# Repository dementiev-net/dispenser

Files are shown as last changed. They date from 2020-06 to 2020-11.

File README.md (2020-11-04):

Дозатор флюса и пасты
=====================

Дозатор с экраном для настройки и отображения режима работы.
При выдавливании есть возможность отката, чтобы снималось напряжение и флюс не продолжал течь.

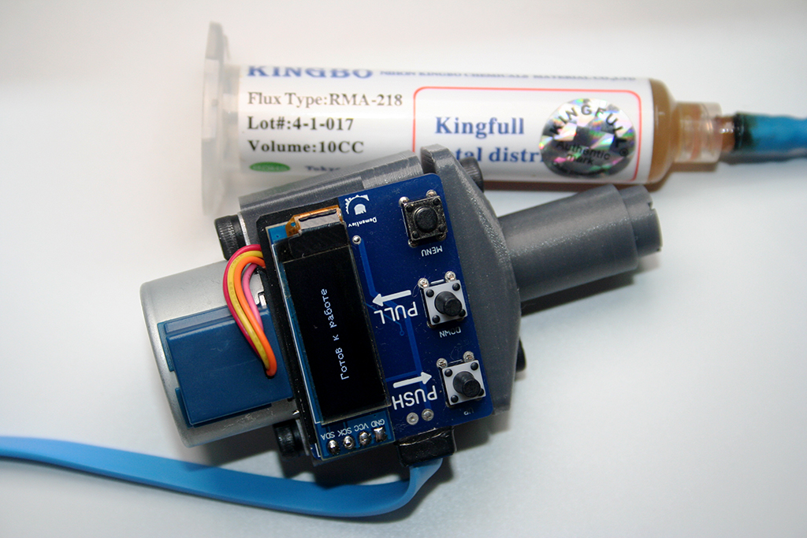
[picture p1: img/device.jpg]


## Плата

Управление:

* При нажатии на **первую кнопку (UP)** происходит выдавливание флюса и откат;
* **Вторая кнопка (DOWN)** отвечает за реверс. Повторное нажатие остановка;
* Чтобы войти в меню удерживается **третья кнопка (MENU)**;

| Верх | Низ
|---|---
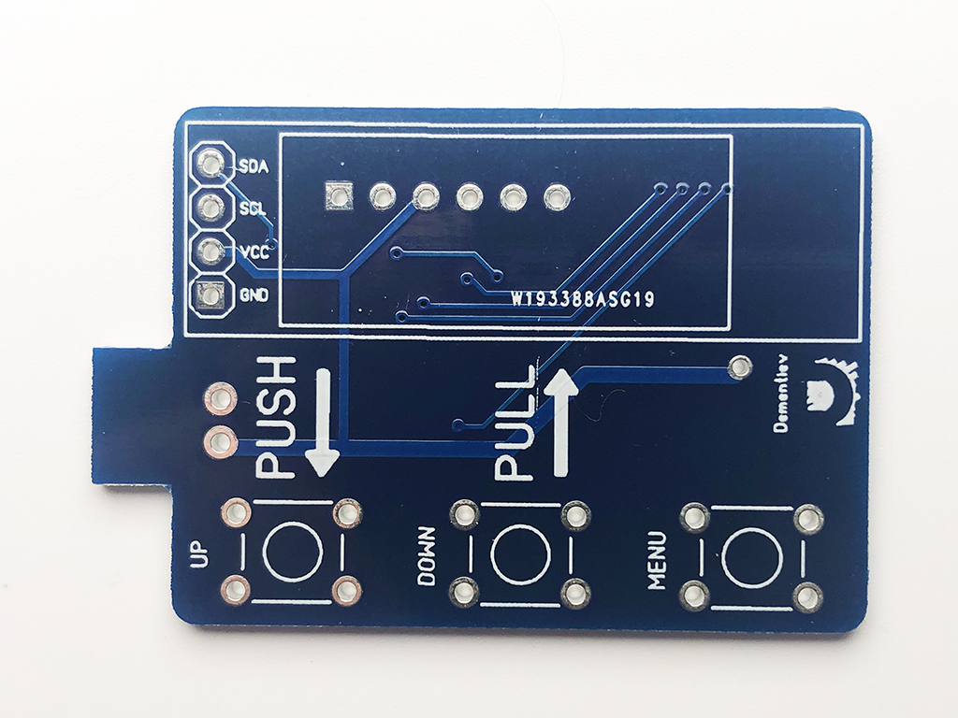
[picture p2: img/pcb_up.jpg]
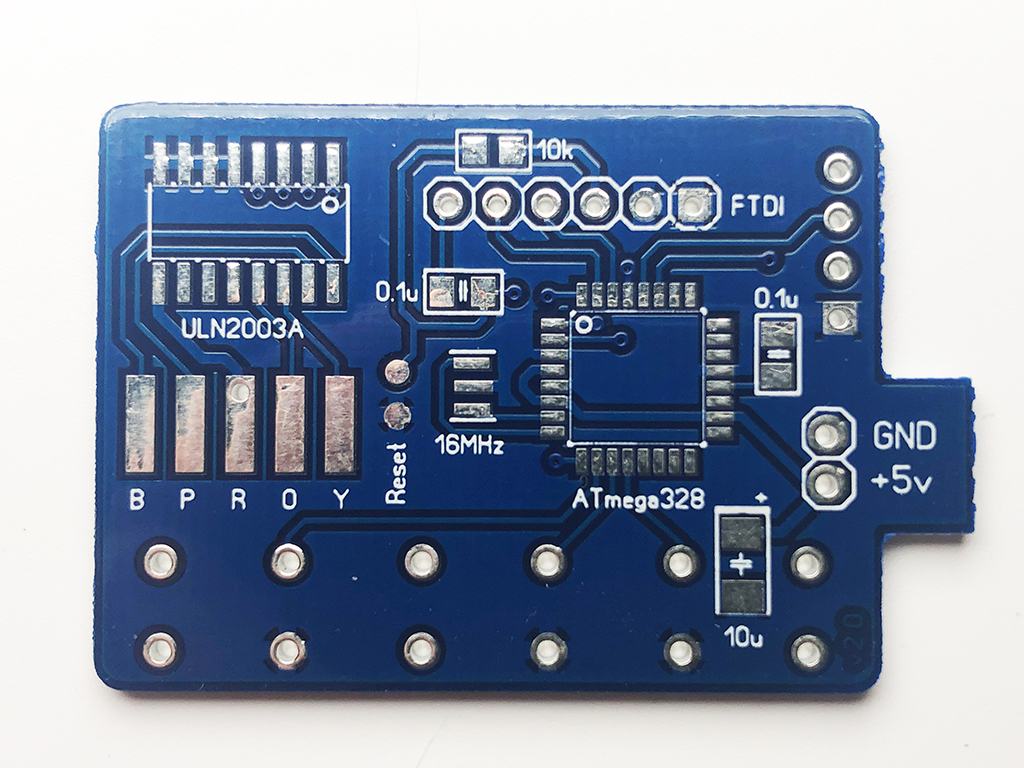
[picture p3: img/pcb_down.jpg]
|  | 
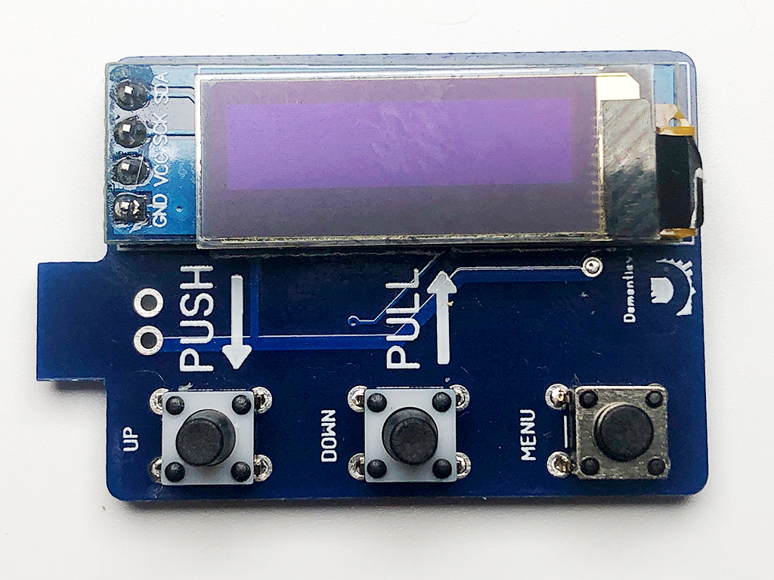
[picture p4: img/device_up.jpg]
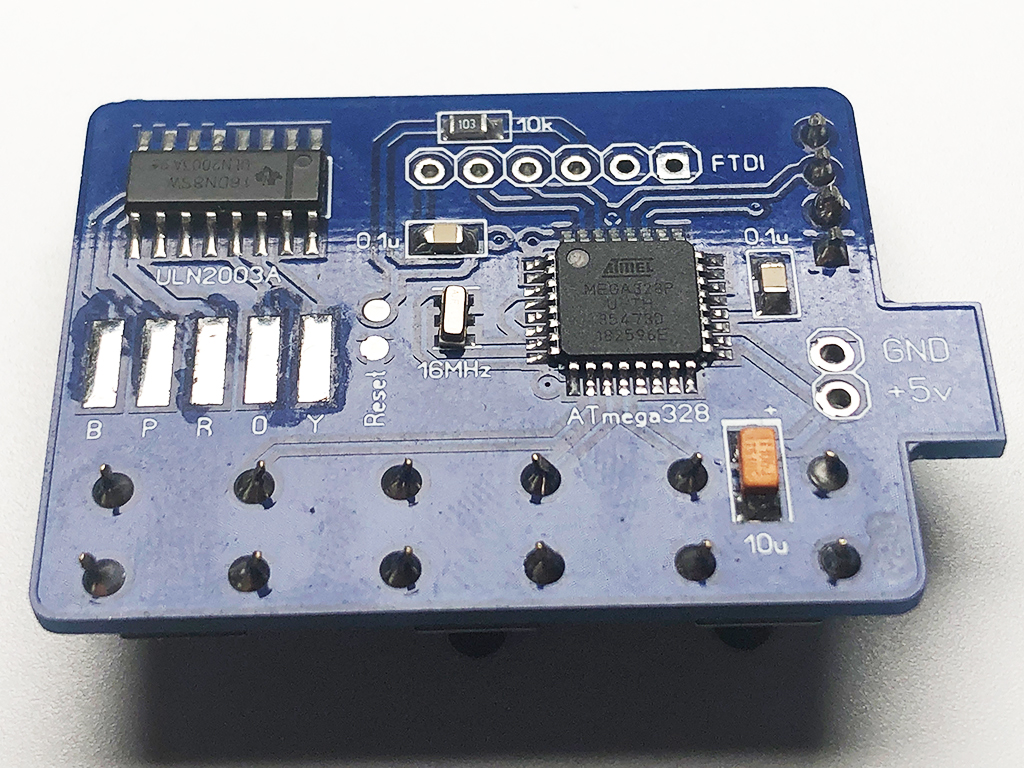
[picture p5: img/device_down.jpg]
|  | 

Экран:

* На **первом экране** настраиваются параметры выдавливания: ускорение, скорость и количество шагов с значениями от 0 до 100 и шагом в 5 пунктов. Листается меню третьей кнопкой а изменяются значения первыми двумя;
* На **втором экране** настройки отвечающие за откат. Значения и управление аналогичны выдавливанию;
* Для **сохранения настроек** в память удерживается третья кнопка;

| Первый экран | Настройки | Настройки
|---|---|---
|  |  | 

#### BOM:

|No|Name|Value|Layer|Comment
|---|---|---|---|---
|1|B1|Button|Top|
|2|B2|Button|Top|
|3|B3|Button|Top|
|4|C1|0.1u|Bottom|0805
|5|C2|0.1u|Bottom|0805
|6|C3|10u|Bottom|Tantal
|7|Q1|16Mhz|Bottom
|8|R1|10k|Bottom|0805
|9|SCREEN|0.91 OLED|Top|I2C 128x32
|10|U1|Atmega328|Bottom|TQFP-32
|11|U2|ULN2003A|Bottom|SO-16

## Корпус

Корпус и поршень с резьбой полностью распечатан на 3D принтере. Есть два варианта крепления платы к корпусу. К первой плата приклеивается на двусторонний скотч или "термоклей", во вторую вставляется. Какой удобнее решайте сами.

| Полный набор | Версии корпуса
|---|---
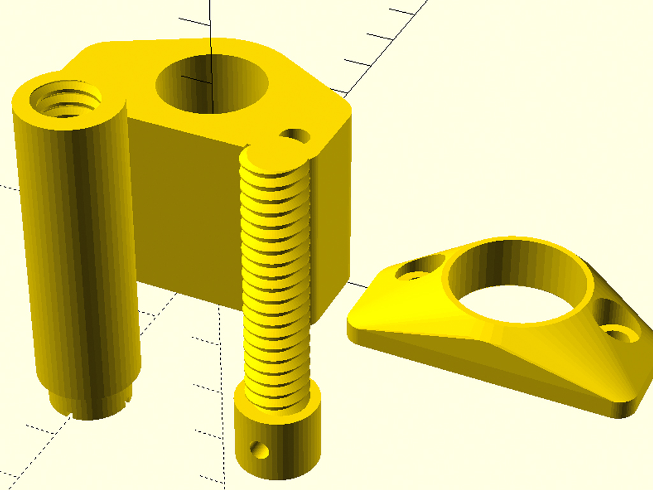
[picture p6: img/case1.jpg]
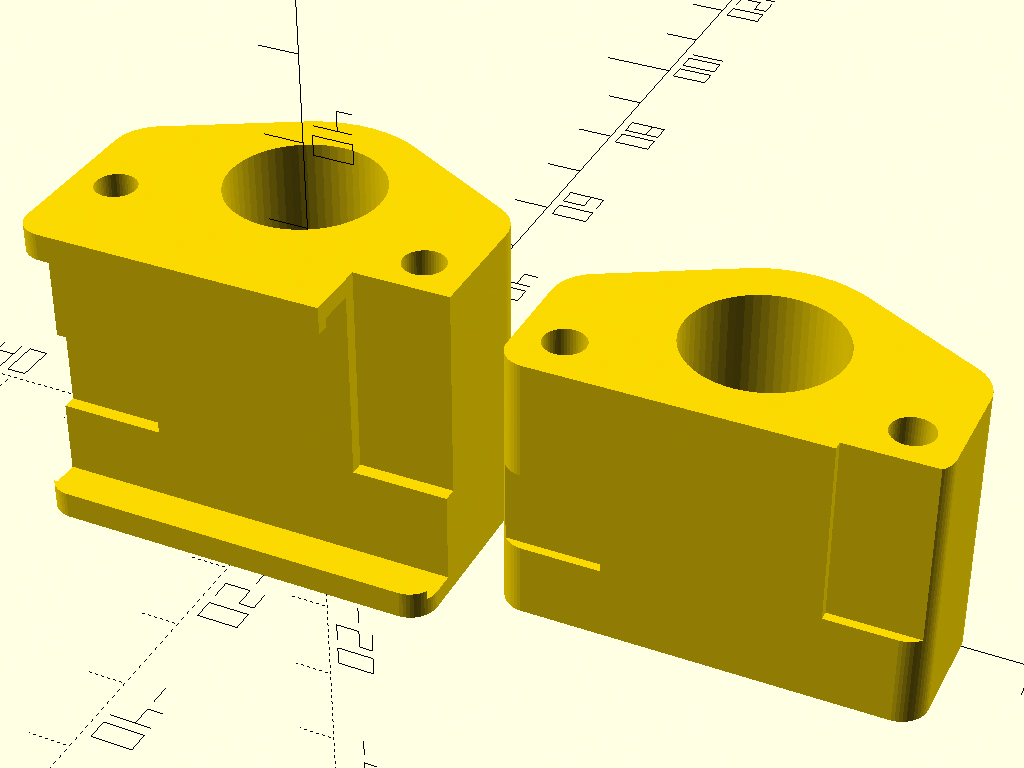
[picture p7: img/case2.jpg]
|  | 

## Прошивка

* Любым программатором загружается bootloader (HEX файл и фьюзы прилагаются). Самой простой вариант прошить через USB Arduino NANO и "сдуть" с нее чип.
* Впаивается чип на плату.
* Заливается INO файл из Arduino IDE (как Arduino NANO) с помощью USB-UART преобразователя (FTDI).

## Контакты

Связаться со мной: info@dementiev.net

##### Лицензия: «Attribution-NonCommercial-ShareAlike»<br>(«Атрибуция — Некоммерческое использование — На тех же условиях») 4.0 Всемирная



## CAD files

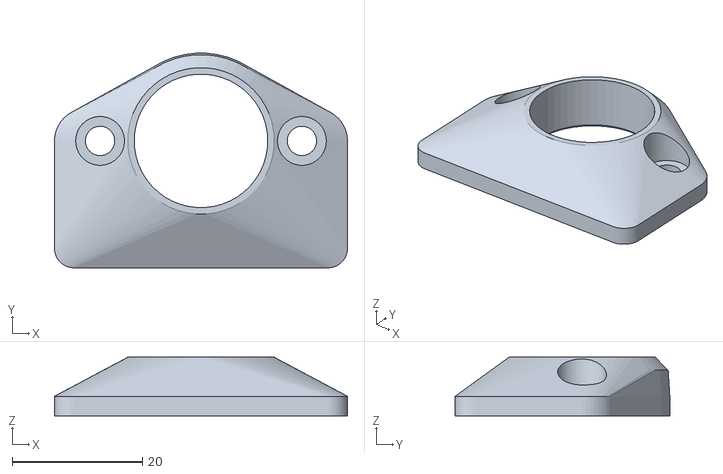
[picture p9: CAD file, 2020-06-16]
3d print/cap v2.stl
45.0 x 33.0 x 9.00

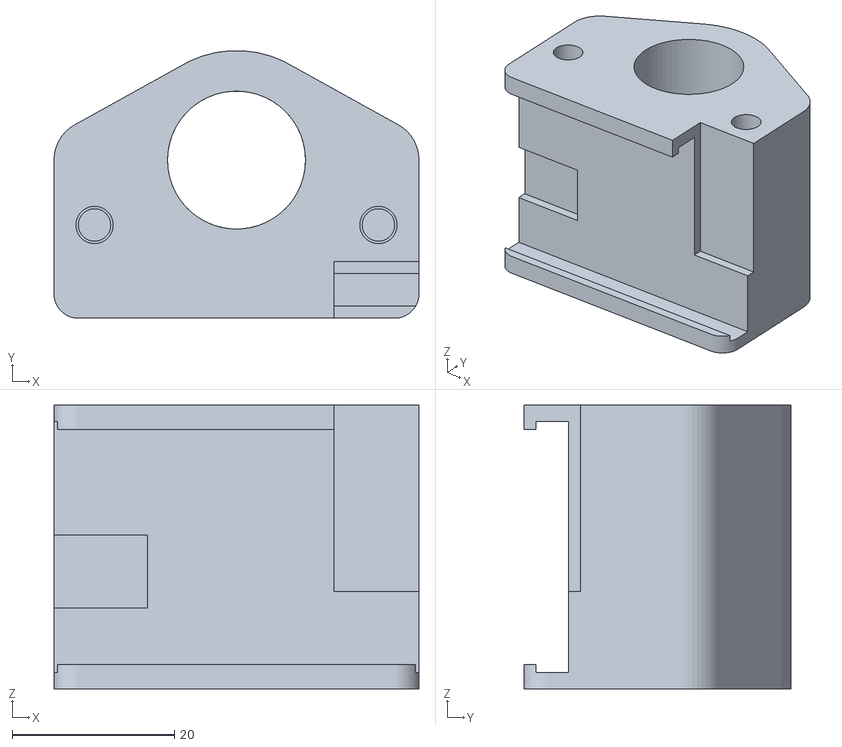
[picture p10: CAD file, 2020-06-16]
3d print/body v2.stl
45.0 x 33.0 x 35.0

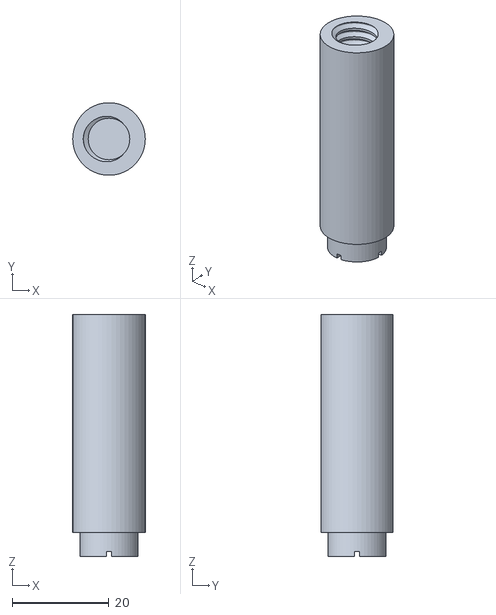
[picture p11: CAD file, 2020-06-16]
3d print/long nut.stl
15.0 x 15.0 x 50.0

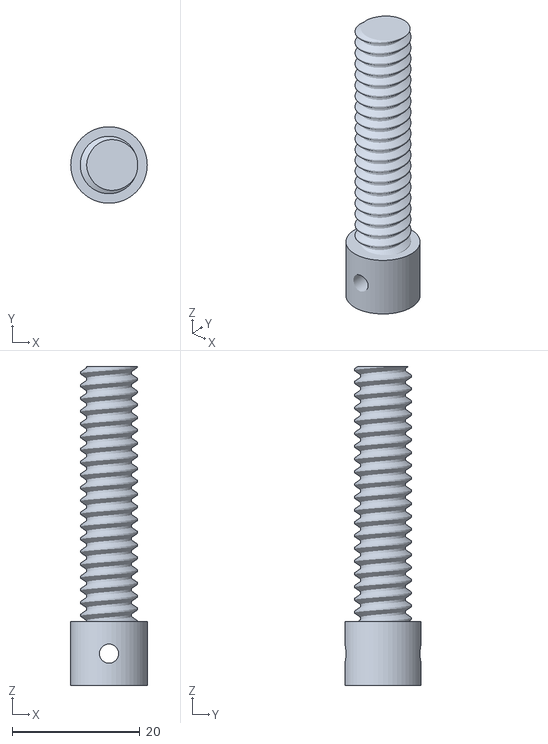
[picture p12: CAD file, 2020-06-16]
3d print/screw..stl
12.0 x 12.0 x 50.0

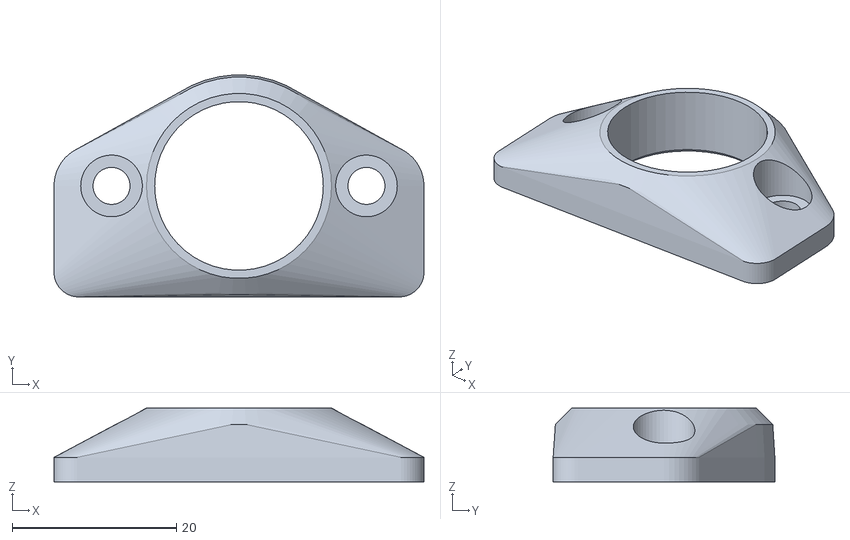
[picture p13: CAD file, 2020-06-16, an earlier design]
3d print/cap v1.stl
45.0 x 27.0 x 9.00

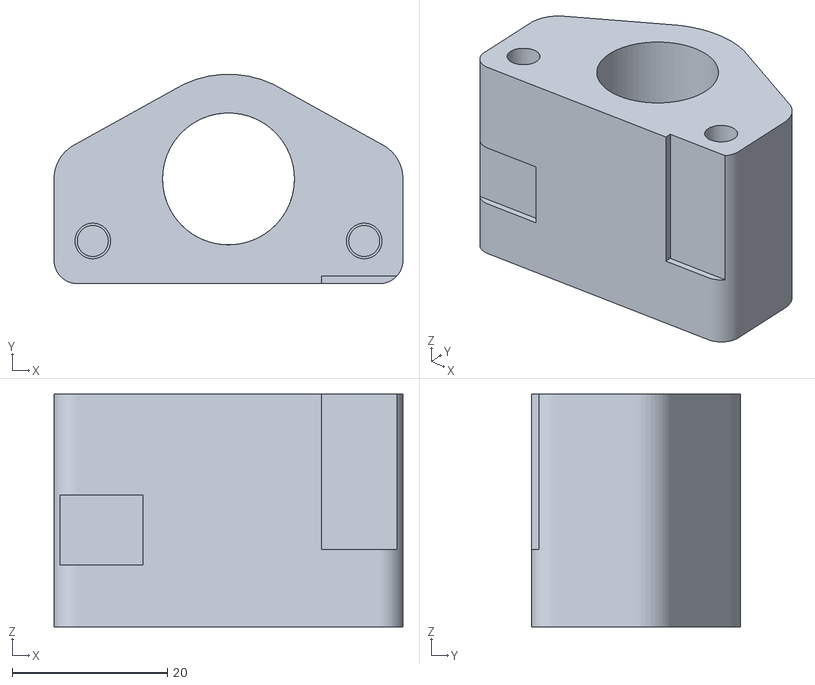
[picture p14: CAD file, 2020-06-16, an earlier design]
3d print/body v1.stl
45.0 x 27.0 x 30.0

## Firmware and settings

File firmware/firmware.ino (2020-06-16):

// ----------------------------------------------------------------------------
// Дозатор паяльной пасты
// версия 2.0 (Atmega328)
// (c) 2020 Дмитрий Дементьев <dementiev@me.com>
// ----------------------------------------------------------------------------

#include <EEPROM.h>
#include "config.h"
#include "button.h"
#include "lcd.h"
#include <AccelStepper.h>

LCD lcd;
LCDData dataScreen;
BUTTON button1;
BUTTON button2;
BUTTON button3;
AccelStepper stepper1(4, 2, 4, 3, 5);
AccelStepper stepper2(4, 2, 4, 3, 5);

int Presets[] = {0, 0, 0, 0, 0};
boolean pull = false; // флаг возврата
int mode = 0; // флаг режима

void setup()
{
  firstRun();
  Presets[0] = EEPROM.read(0); // берем пресеты из EEPROM
  Presets[1] = EEPROM.read(1);
  Presets[2] = EEPROM.read(2);
  Presets[3] = EEPROM.read(3);
  Presets[4] = EEPROM.read(4);
  for (int i = 0; i < 5; i++)
  {
    if (Presets[i] < 0 || Presets[i] > 86400) Presets[i] = 0;
  }
  pinMode(6, INPUT); // входы
  digitalWrite(6, HIGH);
  pinMode(8, INPUT);
  digitalWrite(8, HIGH);
  pinMode(7, INPUT);
  digitalWrite(7, HIGH);
  lcd.init();
  lcd.splashScreen();
  delay(1000);
}

void loop()
{
  byte btn1 = button1.checkButton(6);
  byte btn2 = button2.checkButton(8);
  byte btn3 = button3.checkButton(7);

  /**
     режим работы
  */
  if (mode == 0)
  {
    if (btn1 == 3) mode = 1;
    if (pull == false) lcd.resultScreen("Ujnjd r hf,jnt");
    if (btn2 == 1)
    {
      lcd.resultWork();
      stepper1.setCurrentPosition(0);
      stepper1.setAcceleration(Presets[0] * 10);
      stepper1.setMaxSpeed(Presets[1] * 10);
      stepper1.moveTo(Presets[2] * 10);
      stepper1.runToPosition();
      stepper1.setMaxSpeed(Presets[3] * 10);
      stepper1.moveTo((Presets[2] * 10) -  (Presets[4] * 10));
      stepper1.runToPosition();
    }
    if (pull)
    {
      stepper2.setSpeed(-Presets[3] * 10);
      stepper2.runSpeed();
      lcd.resultScreen("DJPDHFN");
    }
    if (btn3 == 1)
    {
      if (pull == false) pull = true; else pull = false;
    }

    /**
       режим меню
    */
  } else if (mode == 1) {

    dataScreen.menuAccPush   = Presets[0];
    dataScreen.menuSpeedPush = Presets[1];
    dataScreen.menuStepPush  = Presets[2];
    dataScreen.menuSpeedPull = Presets[3];
    dataScreen.menuStepPull  = Presets[4];

    if (btn1 == 1 && dataScreen.cntMM <= 6) dataScreen.cntMM++;
    if (btn1 == 1 && dataScreen.cntMM >= 6) dataScreen.cntMM = 1;
    if (btn2 == 1 && Presets[dataScreen.cntMM - 1] < 100) Presets[dataScreen.cntMM - 1] = Presets[dataScreen.cntMM - 1] + SET_STEP;
    if (btn3 == 1 && Presets[dataScreen.cntMM - 1] > 1) Presets[dataScreen.cntMM - 1]   = Presets[dataScreen.cntMM - 1] - SET_STEP;
    lcd.staticMenu(&dataScreen);

    if (btn1 == 3)
    {
      for (int i = 0; i < 5; i++)
      {
        EEPROM.update(i, Presets[i]);
      }
      mode = 0;
      dataScreen.cntMM = 1;
      lcd.resultScreen("Cj[hfytyj");
      delay(3000);
    }
  }
}

//первый запуск
bool firstRun()
{
  for (uint16_t i; i < sizeof(Presets); i++)
  {
    if (EEPROM.read(i) != 255) return false;
  }
  Presets[0] = MOT_ACC_PUSH;
  Presets[1] = MOT_SPEED_PUSH;
  Presets[2] = MOT_STEP_PUSH;
  Presets[3] = MOT_SPEED_PULL;
  Presets[4] = MOT_STEP_PULL;
  for (int i = 0; i < 5; i++)
  {
    EEPROM.update(i, Presets[i]);
  }
}

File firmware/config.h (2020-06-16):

#ifndef CONFIG_H
#define CONFIG_H

#define BTN_DEBOUNCE      20   // дребезг кнопок (мсек.)
#define BTN_DCGAP         100  // время между двойным кликом (мсек.)
#define BTN_HOLDTIME      1000 // время зажатия кнопки (мсек.)
#define BTN_LONGHOLDTIME  3000 // время долгого нажатия кнопки  (мсек.)

#define SET_STEP          5    // шаг настрек

#define MOT_MAX_SPEED     900  // моторы
#define MOT_ACC_PUSH      50   // (1-100)
#define MOT_SPEED_PUSH    30   // (1-100)
#define MOT_STEP_PUSH     20   // (1-100)
#define MOT_SPEED_PULL    50   // (1-100)
#define MOT_STEP_PULL     5    // (1-100)

#endif

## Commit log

2020-06-16 Init v1.0
    [coupler.stl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]
2020-06-16 Вторая версия
    [Dispenser-[2.0].DRL, Dispenser-[2.0]_copper_bottom.gbr, Dispenser-[2.0]_copper_top.gbr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]
2020-11-04 Поменял описание
2020-11-17 Повторная выгрузка на Github
    [Dispenser-[2.0].DRL, Dispenser-[2.0]_copper_bottom.gbr, Dispenser-[2.0]_copper_top.gbr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]
